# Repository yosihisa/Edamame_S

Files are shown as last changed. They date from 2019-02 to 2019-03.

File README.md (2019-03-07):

# えだまめS  
えだまめSはSOMESATが開発したCanSat入門キットです。  
## 特徴  
実装済みの基板とArduino用のライブラリを用いることにより、簡単にCanSatを作ることができます。  
簡単なプログラムから順番に学んでいくことにより、CanSatの基礎を理解しながら一般的な誘導までできるようになります。  
<br>
基板はバス基板と拡張基板に分かれています。

- バス基板に載っているもの  
  - Arduinoとなるマイコン  
  - GPSモジュール  
  - 地磁気センサ  
  - SDカード  
  - 電源  

- 拡張基板に載っているもの  
  - モータードライバ  
  - モーター  
  - ニクロム線  
  - 電池  

## バス基板の拡張ポート  
この拡張ポートはGPIO,PWM,I2C,UARTなどの機能を割り当てることができます。 
オリジナルCanSatの制御ボードや、他のロボットの制御ボードとして用いることができます。

## 電源について
バス基板の入力電圧は1.7～5.5Vです。  
**絶対に5.5V以上の電圧をかけないようにしてください。**  
Vinと3.3V,GNDをショートさせないように気をつけてください。  
<br>
拡張基板に使用できる電池は**10440型リチウムイオン電池**です。　　

## Arduino IDEへのインストール方法　　
インストールが必要なライブラリは2つあります。
### MightyCore  
このボードをインストールすることにより、えだまめSに搭載されているATmega1284PをArduino IDEからプログラミングできるようになります。  
https://github.com/MCUdude/MightyCore  
### えだまめS ライブラリ
このライブラリをインストールすることにより、えだまめSの各機能を簡単な関数で使うことができるようになります。  
まず、リンク先から最新版のzipをダウンロードします。  
次にArduino IDEの　　

 >  スケッチ>ライブラリをインクルード>.ZIP形式のライブラリをインストール  
 
 を開き、ダウンロードしたZIPファイルを選択します。  
 ダウンロード先 → https://github.com/yosihisa/Edamame_S/releases  

 # 注意事項  
 えだまめSプロジェクトはまだ未完成です。  
 利用は自己責任でお願いします。  
 <br>
 各種解説ページは準備中です。  
 
 連絡先 [@n_yosihisa](https://twitter.com/n_yosihisa)

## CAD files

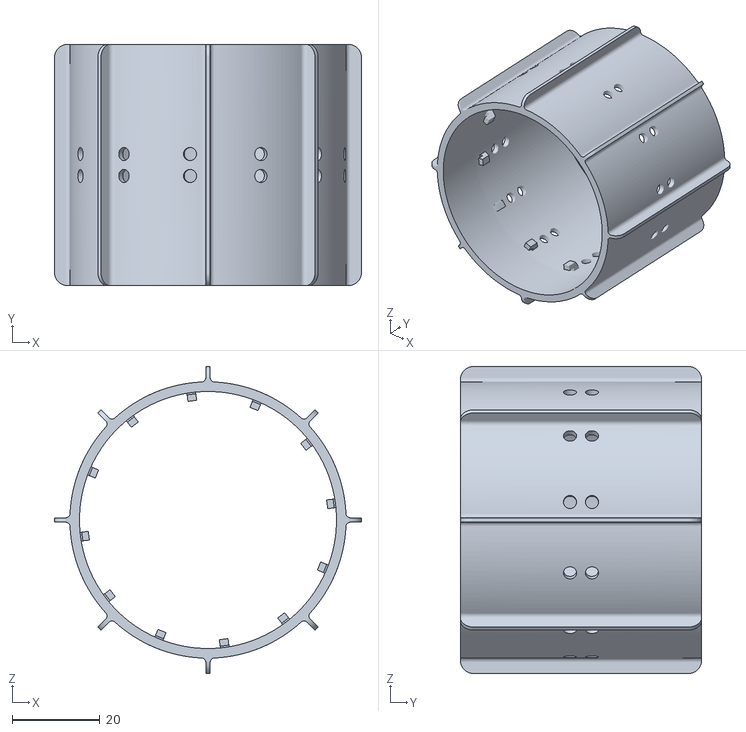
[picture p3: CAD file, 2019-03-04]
STL/Tire.stl
70.0 x 55.0 x 70.0

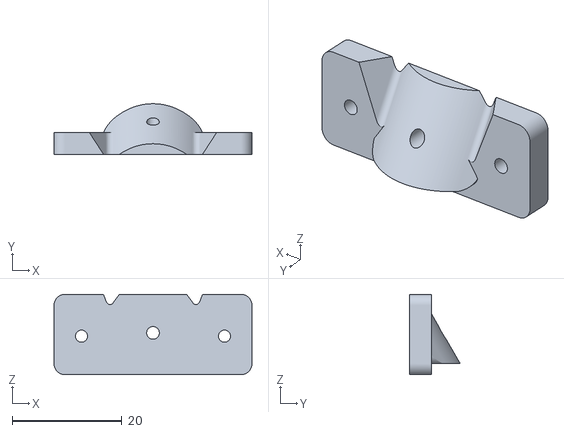
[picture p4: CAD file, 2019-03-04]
STL/TailFixture_2.stl
36.0 x 9.19 x 14.6

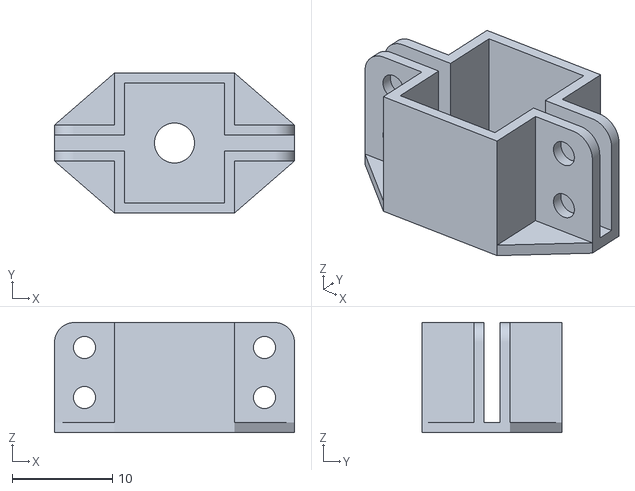
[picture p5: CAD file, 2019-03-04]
STL/MotorFixture.stl
24.0 x 14.0 x 11.0

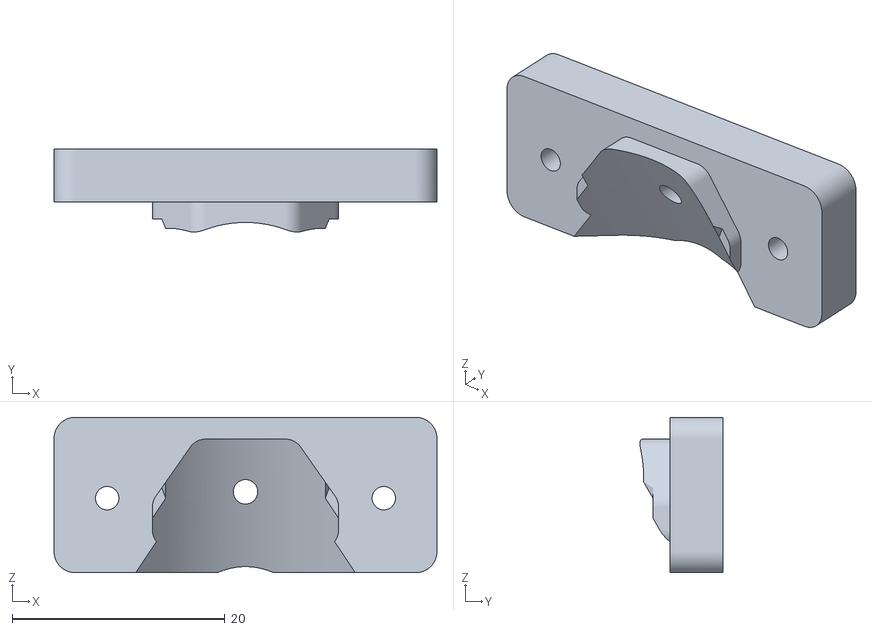
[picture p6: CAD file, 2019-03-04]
STL/TailFixture_1.stl
36.0 x 7.83 x 14.6

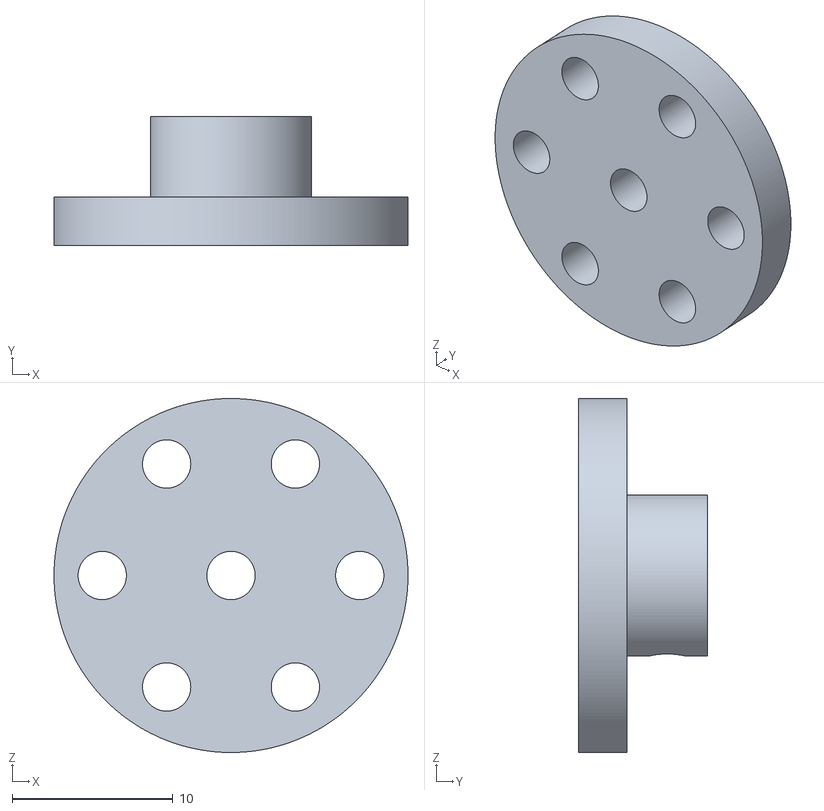
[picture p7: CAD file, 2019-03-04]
STL/Hub.stl
22.0 x 8.00 x 22.0

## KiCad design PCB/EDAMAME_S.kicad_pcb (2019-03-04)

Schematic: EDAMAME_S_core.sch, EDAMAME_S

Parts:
C2, C3, C4, C5, C6, C10, C12, C16: 0.1u; C_0603_1608Metric_Pad1.05x0.95mm_HandSolder
C7, C8, C15: 10u; C_0805_2012Metric_Pad1.15x1.40mm_HandSolder
C9: 100u; C_1206_3216Metric_Pad1.42x1.75mm_HandSolder
C11: 0.22F 3.3V; MS621FE_FL11E
C13, C14: 47p; C_0603_1608Metric_Pad1.05x0.95mm_HandSolder
CN1: USB-B-MICRO; Micro-USB
D1, D2, D6: GS1010FL; D_SOD-123F
D3: POWER; LED_0603_1608Metric_Pad1.05x0.95mm_HandSolder
D4: LED1; LED_0603_1608Metric_Pad1.05x0.95mm_HandSolder
D5: LED2; LED_0603_1608Metric_Pad1.05x0.95mm_HandSolder
D7: 1PPS; LED_0603_1608Metric_Pad1.05x0.95mm_HandSolder
D8: TX_LED; LED_0603_1608Metric_Pad1.05x0.95mm_HandSolder
D9: RX_LED; LED_0603_1608Metric_Pad1.05x0.95mm_HandSolder
J1: Conn; PinHeader_2x19_P2.54mm_Vertical
J2: ISP; AVR_ISP
L1: 2.2uH; inductor_VLF4012-2R2
R1, R2, R3, R4, R5: 10k; R_0603_1608Metric_Pad1.05x0.95mm_HandSolder
R6, R7: 2.2k; R_0603_1608Metric_Pad1.05x0.95mm_HandSolder
R8, R9, R10, R12, R15, R16: 1k; R_0603_1608Metric_Pad1.05x0.95mm_HandSolder
R11: 100; R_0603_1608Metric_Pad1.05x0.95mm_HandSolder
R13, R14: 33; R_0603_1608Metric_Pad1.05x0.95mm_HandSolder
U1: microSD
U2: ATMEGA1284P-MU; QFN-44-1EP_7x7mm_P0.5mm_EP5.15x5.15mm
U3: LSM303C; LGA-12_2x2mm_P0.5mm_HandSolder
U4: TPS63001; Texas_S-PVSON-N10_ThermalVias
U5: GYSFDMAXB
U6: FT231XQ; QFN-20-1EP_4x4mm_P0.5mm_EP2.5x2.5mm
Y1: 12MHz; Resonator_SMD_muRata_CSTxExxV-3Pin_3.0x1.1mm

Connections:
+3V3: C2.1, C3.1, C4.1, C5.1, C8.1, C9.1, C10.1, J1.5, J1.6, R1.2, R2.2, R3.2, R4.2, R5.1, R6.1, R7.1, R8.2, R11.1, R15.1, R16.1, U1.4, U2.5 (VCC), U2.17 (VCC), U2.27 (AVCC), U2.38 (VCC), U3.2, U3.3, U3.9, U3.10, U4.1, U4.10, U5.16, U6.20
+5V: C15.1, C16.1, CN1.1, D2.2, U6.11, U6.12
/EDAMAME_S_core/0: J1.9, U2.40 ((PCINT8/T0/XCK)PB0)
/EDAMAME_S_core/1: J1.11, U2.41 ((PCINT9/CLKO/T1)PB1)
/EDAMAME_S_core/2: J1.13, U2.42 ((PCINT10/AIN0/INT2)PB2)
/EDAMAME_S_core/3-: J1.15, U2.43 ((PCINT11/AIN1/OC0)PB3)
/EDAMAME_S_core/12-: J1.25, U2.13 ((PCINT28/XCK1/OC1B)PD4)
/EDAMAME_S_core/13-: J1.27, U2.14 ((PCINT294/OC1A)PD5)
/EDAMAME_S_core/14-: J1.29, U2.15 ((PCINT30/OC2B/ICP)PD6)
/EDAMAME_S_core/15-: J1.31, U2.16 ((PCINT31/OC2A)PD7)
/EDAMAME_S_core/18: D5.2, J1.36, U2.21 ((PCINT18/TCK)PC2)
/EDAMAME_S_core/19: D4.2, J1.34, U2.22 ((PCINT19/TMS)PC3)
/EDAMAME_S_core/20: J1.32, U2.23 ((PCINT20/TDO)PC4)
/EDAMAME_S_core/21: J1.30, U2.24 ((PCINT21/TDI)PC5)
/EDAMAME_S_core/22: J1.28, U2.25 ((PCINT22/TOSC1)PC6)
/EDAMAME_S_core/23: J1.26, U2.26 ((PCINT23/TOSC2)PC7)
/EDAMAME_S_core/A0: J1.24, U2.37 ((PCINT0/ADC0)PA0)
/EDAMAME_S_core/A1: J1.22, U2.36 ((PCINT1/ADC1)PA1)
/EDAMAME_S_core/A2: J1.20, U2.35 ((PCINT2/ADC2)PA2)
/EDAMAME_S_core/A3: J1.18, U2.34 ((PCINT3/ADC3)PA3)
/EDAMAME_S_core/A4: J1.16, U2.33 ((PCINT4/ADC4)PA4)
/EDAMAME_S_core/A5: J1.14, U2.32 ((PCINT5/ADC5)PA5)
/EDAMAME_S_core/A6: J1.12, U2.31 ((PCINT6/ADC6)PA6)
/EDAMAME_S_core/A7: J1.10, U2.30 ((PCINT7/ADC7)PA7)
/EDAMAME_S_core/AVR→GPS: J1.23, U2.12 ((PCINT27/TXD1/INT1)PD3), U5.3
/EDAMAME_S_core/AVR→PC: J1.19, U2.10 ((PCINT25/TXD0)PD1), U6.1
/EDAMAME_S_core/GPS→AVR: J1.21, U2.11 ((PCINT26/RXD1/INT0)PD2), U5.5
/EDAMAME_S_core/I2C_SCL: J1.33, R7.2, U2.19 ((PCINT16/SCL)PC0), U3.1
/EDAMAME_S_core/I2C_SDA: J1.35, R6.2, U2.20 ((PCINT17/SDA)PC1), U3.4
/EDAMAME_S_core/MISO: J2.1, R4.1, U1.7, U2.2 ((PCINT14/MISO)PB6)
/EDAMAME_S_core/MOSI: J2.4, R2.1, U1.3, U2.1 ((PCINT13/MOSI)PB5)
/EDAMAME_S_core/PC→AVR: J1.17, U2.9 ((PCINT24/RXD0)PD0), U6.17
/EDAMAME_S_core/RST: C12.2, J2.5, R5.2, U2.4 (~RESET)
/EDAMAME_S_core/SCK: J2.3, R3.1, U1.5, U2.3 ((PCINT15/SCK)PB7)
/EDAMAME_S_core/SS: R1.1, U1.2, U2.44 ((PCINT12/OC0B/~SS~)PB4)
GND: C2.2, C3.2, C4.2, C5.2, C6.2, C7.2, C8.2, C9.2, C10.2, C11.2, C13.2, C14.2, C15.2, C16.2, CN1.5, CN1.6, CN1.7, D3.1, D7.1, J1.7, J1.8, J1.37, J1.38, J2.6, R9.2, R10.2, U1.6, U2.6 (GND), U2.18 (GND), U2.28 (GND), U2.39 (GND), U3.6, U3.8, U4.3, U4.9, U4.11, U5.1, U5.2, U5.7, U5.10, U5.12, U5.19, U5.20, U6.3, U6.13, U6.21, Y1.2
unnamed: C6.1, U3.5
unnamed: C7.1, D1.1, D2.1, U4.5, U4.6, U4.7, U4.8
unnamed: C11.1, D6.1, U5.14
unnamed: C12.1, U6.18
unnamed: C13.1, CN1.3, R14.2
unnamed: C14.1, CN1.2, R13.2
unnamed: D1.2, J1.1, J1.2, J1.3, J1.4
unnamed: D3.2, R8.1
unnamed: D4.1, R9.1
unnamed: D5.1, R10.1
unnamed: D6.2, R11.2
unnamed: D7.2, R12.1
unnamed: D8.1, U6.15
unnamed: D8.2, R15.2
unnamed: D9.1, U6.14
unnamed: D9.2, R16.2
unnamed: L1.1, U4.4
unnamed: L1.2, U4.2
unnamed: R12.2, U5.6
unnamed: R13.1, U6.9
unnamed: R14.1, U6.8
unnamed: U2.7 (XTAL2), Y1.1
unnamed: U2.8 (XTAL1), Y1.3

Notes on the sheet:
Vin 2.7-5.5V Vout 3.3V 800mA

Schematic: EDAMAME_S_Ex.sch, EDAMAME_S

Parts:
BT1: 10440; BH-411
C17, C19: 10u; C_0805_2012Metric_Pad1.15x1.40mm_HandSolder
C18: 0.1u; C_0603_1608Metric_Pad1.05x0.95mm_HandSolder
D10: Nichrome; LED_0603_1608Metric_Pad1.05x0.95mm_HandSolder
D11: POWER; LED_0603_1608Metric_Pad1.05x0.95mm_HandSolder
J3: Conn; PinHeader_1x19_P2.54mm_Vertical
J4: Nichrome; MPT0.5_2-2.54
J5: FlightPin; PinHeader_1x02_P2.54mm_Horizontal
M1: Motor_L; JST_XH_B02B-XH-A_1x02_P2.50mm_Vertical
M2: Motor_R; JST_XH_B02B-XH-A_1x02_P2.50mm_Vertical
Q1: MTM231102LBF; SOT-323_SC-70
Q2: 2SC2712; SOT-23
R17, R19, R22: 10K; R_0603_1608Metric_Pad1.05x0.95mm_HandSolder
R18, R21: 1K; R_0603_1608Metric_Pad1.05x0.95mm_HandSolder
R20: 10m; R_2512_6332Metric_Pad1.52x3.35mm_HandSolder
SW1: power; SS-12D01-VG4
U7, U9: BD6211F; SOIC-8_3.9x4.9mm_P1.27mm
U8: INA226; MSOP-10_3x3mm_P0.5mm

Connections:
+BATT: C17.1, C19.1, J3.1, J3.2, Q1.2, R17.2, R20.1, R21.1, U7.2, U7.3, U7.6, U8.8, U8.9, U9.2, U9.3, U9.6
/EDAMAME_S_Ex/FlightPin: J3.5, J5.1, R22.1
/EDAMAME_S_Ex/MOTOR_LF: J3.13, U7.4
/EDAMAME_S_Ex/MOTOR_LR: J3.14, U7.5
/EDAMAME_S_Ex/MOTOR_RF: J3.16, U9.5
/EDAMAME_S_Ex/MOTOR_RR: J3.15, U9.4
/EDAMAME_S_Ex/Nichrome: J3.8, R19.2
/EDAMAME_S_Ex/SCL: J3.17, U8.5
/EDAMAME_S_Ex/SDA: J3.18, U8.4
GNDPWR: BT1.2, C17.2, C18.2, C19.2, D10.1, D11.1, J3.4, J3.19, J4.2, J5.2, Q2.2, U7.8, U8.7, U9.8
unnamed: BT1.1, SW1.2
unnamed: D10.2, R18.2
unnamed: D11.2, R21.2
unnamed: J4.1, Q1.3, R18.1
unnamed: M1.1, U7.1
unnamed: M1.2, U7.7
unnamed: M2.1, U9.1
unnamed: M2.2, U9.7
unnamed: Q1.1, Q2.3, R17.1
unnamed: Q2.1, R19.1
unnamed: R20.2, SW1.1, U8.10
VCC: C18.1, J3.3, R22.2, U8.1, U8.2, U8.6

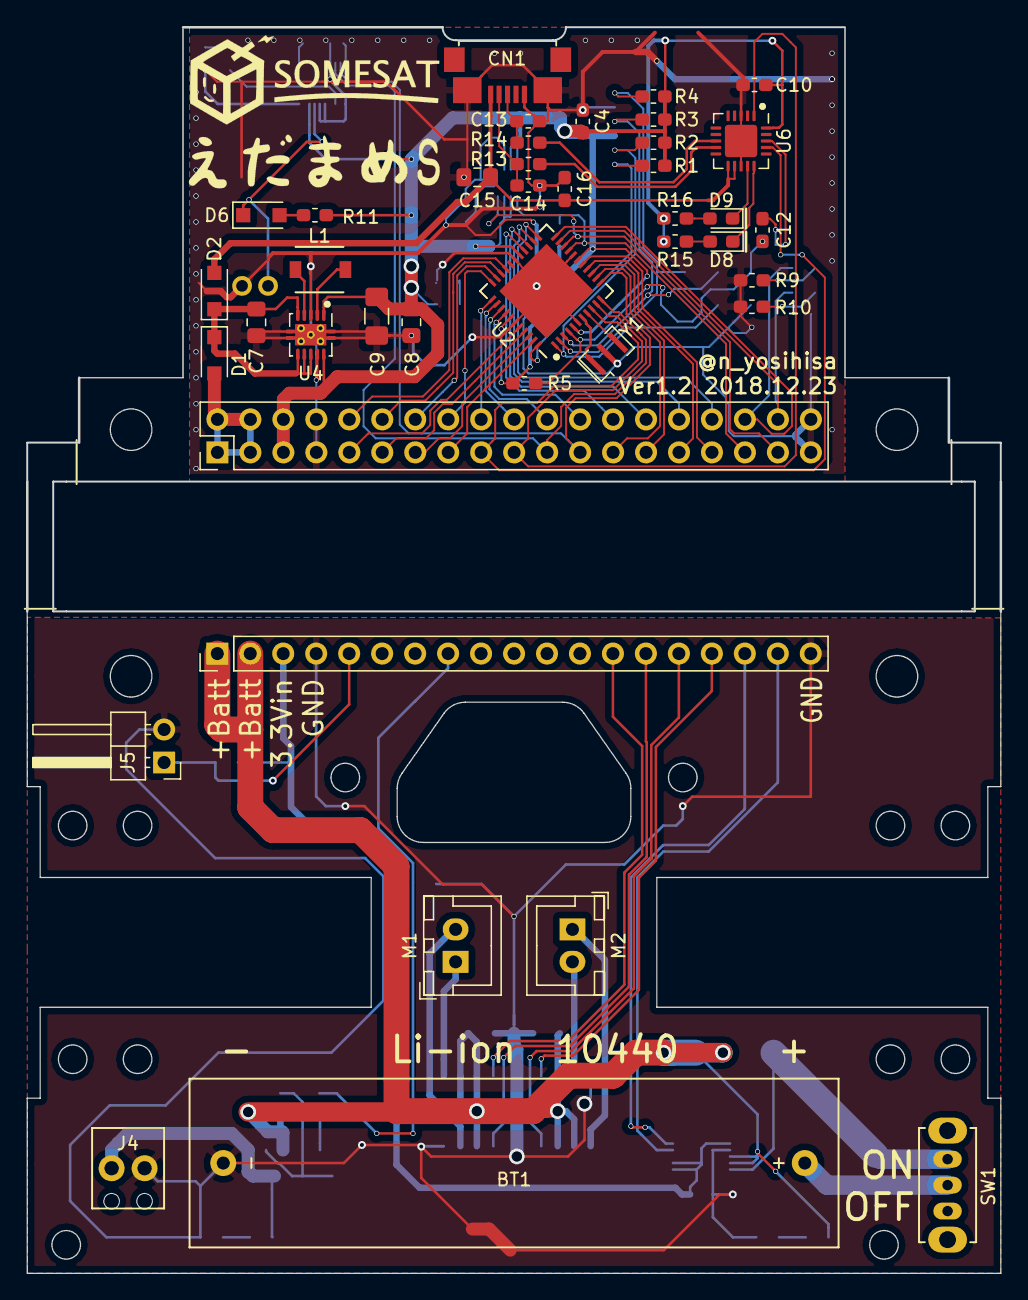
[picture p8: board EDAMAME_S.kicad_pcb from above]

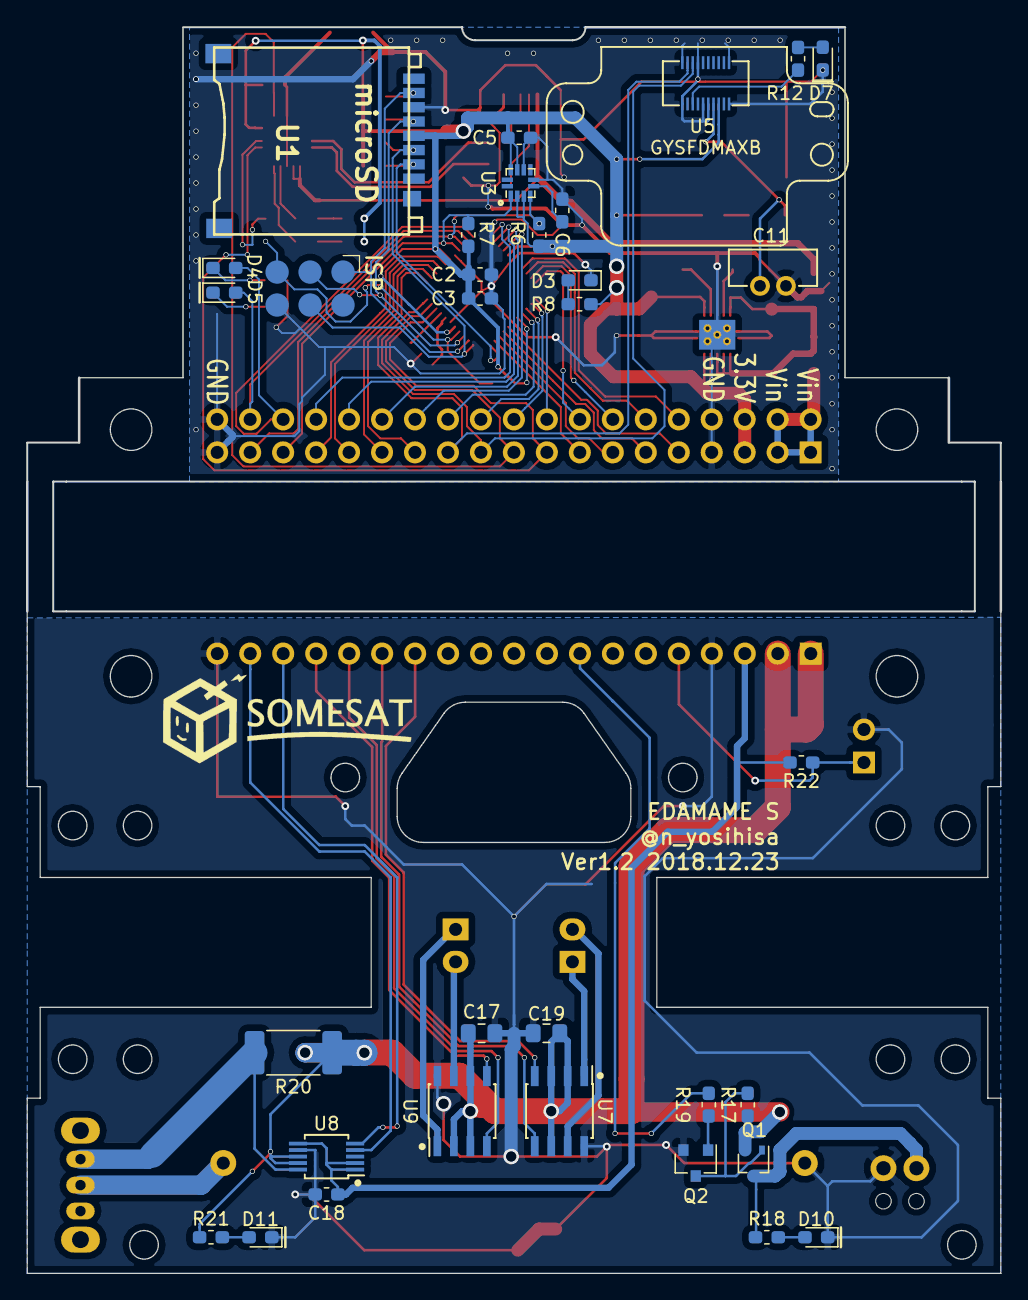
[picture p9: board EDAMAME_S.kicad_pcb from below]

Board: 2 copper layers, 75.0 x 96.0 mm, 74 parts (32 on the bottom side), 81 nets.

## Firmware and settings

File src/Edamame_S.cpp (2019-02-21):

#include "Edamame_S.h"
#include <string.h>

void LSM303_init_m() {
	Wire.beginTransmission(LSM303AGR_M);
	Wire.write(0x60);
	Wire.write(0b00001101);
	Wire.endTransmission(true);
	Wire.beginTransmission(LSM303AGR_M);
	Wire.write(0x61);
	Wire.write(0b00000100);
	Wire.endTransmission(true);
	Wire.beginTransmission(LSM303AGR_M);
	Wire.write(0x62);
	Wire.write(0b00010000);
	Wire.endTransmission(true);
}

void LSM303_update_m(struct xyza *data) {

	Wire.beginTransmission(LSM303AGR_M);
	Wire.write(0x60);
	Wire.write(0b00001101);
	Wire.endTransmission(true);

	Wire.beginTransmission(LSM303AGR_M);
	Wire.write(0x68);
	Wire.endTransmission(false);
	Wire.requestFrom((uint8_t)LSM303AGR_M, (uint8_t)6);
	data->x = Wire.read();
	data->x += (Wire.read() << 8);
	data->y = Wire.read();
	data->y += (Wire.read() << 8);
	data->z = Wire.read();
	data->z += (Wire.read() << 8);

	data->x = data->x - data->x_offset;
	data->y = data->y - data->y_offset;
	data->z = data->z - data->z_offset;
	data->arg = atan2((float)-data->y, (float)data->x);

}

void set_gpsHiSpeed() {
	Serial_GPS.print("$PMTK220,100*2F\r\n");
	delay(100);
	Serial_GPS.print("$PMTK314,0,0,0,1,0,0,0,0,0,0,0,0,0,0,0,0,0,0,0*29\r\n");
	delay(100);
}
/*
long split_GPGGA(char msg[], char buff) {
	for (unsigned int i = 0; msg[i] != c; i++) {

	}
}*/

char get_gps_1() {
	while (1) {
		long data = Serial_GPS.read();
		if (data != -1) {
			char c = (char)data;
			return data;
		}
	}
}

long get_gps(struct gps *gps_data, unsigned long t) {
	gps_data->latitude = 0;
	gps_data->longitude = 0;
	gps_data->hh = 0;
	gps_data->mm = 0;
	gps_data->ss = 0;

	char c, gps_msg[100];
	long dd, mm, mmmm, ddd, dddd;
	unsigned long time = millis();

	while (Serial_GPS.available())Serial_GPS.read();

	while (millis()-time < t) {

		c = get_gps_1();
		if (c == '$') {
			for (long i = 0; i < 6; i++) {
				c = get_gps_1();
				gps_msg[i] = c;
			}
			if (strncmp(gps_msg, "GPGGA", 5) == 0) {
				for (long i = 0; c != '\n'; i++) {
					c = get_gps_1();
					gps_msg[i] = c;

					if (c == '\n') {
						gps_data->hh = 10 * (gps_msg[0] - 48) + (gps_msg[1] - 48);
						gps_data->mm = 10 * (gps_msg[2] - 48) + (gps_msg[3] - 48);
						gps_data->ss = 10 * (gps_msg[4] - 48) + (gps_msg[5] - 48);
						if (gps_msg[6] != '.')gps_data->mode = -1;
						gps_data->ms = 100 * (gps_msg[7] - 48) + 10*(gps_msg[8] - 48)+(gps_msg[9] - 48);
						if (gps_data->hh < 0 || gps_data->hh > 24)gps_data->mode = -1;

						
						if (i > 40) {
							long n;
							dd = 0;
							for (n = 5; n < i; n++) {
								if (gps_msg[n] == ',') {
									dd = 10 * (gps_msg[n + 1] - 48) + (gps_msg[n + 2] - 48);
									mm = 10 * (gps_msg[n + 3] - 48) + (gps_msg[n + 4] - 48);
									mmmm = 1000 * (gps_msg[n + 6] - 48) + 100 * (gps_msg[n + 7] - 48) + 10 * (gps_msg[n + 8] - 48) + (gps_msg[n + 9] - 48);

									gps_data->latitude = (dd + (((double)mm + (double)mmmm / 10000) / 60)) * 1000000;
									if (gps_msg[n + 10] != ',' || gps_msg[n + 11] != 'N')gps_data->mode = -1;
									break;
								}
							}
							for (n = n + 1; n < i; n++) {
								if (gps_msg[n] == 'N') {
									break;
								}
							}
							for (n = n + 1; n < i; n++) {
								if (gps_msg[n] == ',') {
									ddd = 100 * (gps_msg[n + 1] - 48) + 10 * (gps_msg[n + 2] - 48) + (gps_msg[n + 3] - 48);
									mm = 10 * (gps_msg[n + 4] - 48) + (gps_msg[n + 5] - 48);
									mmmm = 1000 * (gps_msg[n + 7] - 48) + 100 * (gps_msg[n + 8] - 48) + 10 * (gps_msg[n + 9] - 48) + (gps_msg[n + 10] - 48);
									gps_data->longitude = (ddd + (((double)mm + (double)mmmm / 10000) / 60)) * 1000000;
									if (gps_msg[n + 11] != ',' || gps_msg[n + 12] != 'E')gps_data->mode = -1;
									break;
								}
							}
							for (n = n + 1; n < i; n++) {
								if (gps_msg[n] == 'E') {
									break;
								}
							}
							for (n = n + 1; n < i; n++) {
								if (gps_msg[n] == ',') {
									gps_data->mode = (gps_msg[n + 1] - 48);
									break;
								}
							}
						}
						else {
							gps_data->mode = 0;
						}
						if (gps_data->mode == -1) {
							gps_data->latitude = 0;
							gps_data->longitude = 0;
						} else {
							return gps_data->mode;
						}
					}
				}
			}
		}
	}
	return -1;
}


void calc_gps(struct gps *gps_data, long latitude, long longitude) {
	
	long dx = latitude - gps_data->latitude;	//南北　北が正
	long dy = longitude - gps_data->longitude;	//東西　東が正
	gps_data->arg = atan2(dy, dx);
	gps_data->dist = dx * dx + dy * dy;
}

void print_data(control_data *data) {
	String str = "\n";

	str.concat("\nMODE         ");
	str.concat(data->mode);
	str.concat("           Log_num  ");
	str.concat(data->log_num);

	str.concat("\nTIME         ");
	str.concat(data->gps_data.hh);
	str.concat(":");
	str.concat(data->gps_data.mm);
	str.concat(":");
	str.concat(data->gps_data.ss);
	str.concat(".");
	str.concat(data->gps_data.ms);

	str.concat("\nPOWER        ");
	str.concat(data->voltage);
	str.concat("mV ");
	str.concat(data->current);
	str.concat("mA");

	str.concat("\nGPS          ");
	str.concat("mode:");
	str.concat(data->gps_data.mode);
	str.concat(" N: ");
	str.concat(data->gps_data.latitude);
	str.concat(" E: ");
	str.concat(data->gps_data.longitude);
	str.concat("  dist: ");
	str.concat(data->gps_data.dist);


	str.concat("\nLSM303       ");
	str.concat("x:");
	str.concat(data->LSM303_data.x);
	str.concat(" y:");
	str.concat(data->LSM303_data.y);


	str.concat("\nArg          ");
	str.concat(data->arg);
	str.concat(" (GPS: ");
	str.concat(data->gps_data.arg);
	str.concat(", LSM303: ");
	str.concat(data->LSM303_data.arg);
	str.concat(")");

	str.concat("\nFlight Pin   ");
	str.concat(data->flightPin);

	str.concat("\nmotor        (");
	str.concat(data->motor_L);
	str.concat(" , ");
	str.concat(data->motor_R);
	str.concat(")  nichrome: ");
	str.concat(data->nichrome);

	str.concat("\n");
	Serial_PC.print(str);
	return;
}
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

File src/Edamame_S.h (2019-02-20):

#ifndef _Edamame_S_h
#define _Edamame_S_h

#include <Arduino.h>
#include <Wire.h>
#include <SD.h>

#define LSM303AGR_A 0x19
#define LSM303AGR_M 0x1E
#define SD_CS       4
#define LED0        18
#define LED1        19
#define Serial_PC   Serial
#define Serial_GPS  Serial1

struct xyza {
    int16_t x,y,z;
    int16_t x_offset=0;
    int16_t y_offset=0;
    int16_t z_offset=0;
    float arg;
};

struct gps {
	long latitude;
	long longitude;
	uint8_t hh, mm, ss;
	uint16_t ms;

	int mode = 0;

	float arg = 0;
	unsigned long dist = 0;
};

struct control_data {
	String log_path = "";
	long log_num = 0;
	int mode = 0;
	int flightPin = 0;

	long voltage = 0;
	long current = 0;

	struct gps gps_data;
	struct xyza LSM303_data;

	float arg = 0;

	int  motor_L = 0, motor_R = 0, nichrome = 0;

};

void LSM303_init_m();
void LSM303_update_m(struct xyza *data);

void set_gpsHiSpeed();
long get_gps(struct gps *gps_data , unsigned long t);
void calc_gps(struct gps *gps_data, long latitude, long longitude);

void print_data(control_data *data);
void write_data(control_data *data);

#endif

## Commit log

2019-02-15 Ver0.1.0
    Add library
    Ad ex01-03,05 (LED,UART,PWM,I2C)
2019-02-20 Add Calibration
2019-02-21 Fixed Sign of longitude
    [Edamame_S.cpp]
2019-02-22 Add STL
    [Hub.stl, MotorFixture.stl, TailFixture_1.stl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]
2019-02-22 Fixed Motor rotation direction
2019-03-04 Add PCB (0.2mmビアあり)
    [EDAMAME_S.kicad_pcb, EDAMAME_S.sch, EDAMAME_S_Ex.sch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]
